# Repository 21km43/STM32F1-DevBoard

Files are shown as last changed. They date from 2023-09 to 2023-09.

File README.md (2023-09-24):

# STM32F1 Development Board

## Summary
Schematic and Board layout of STM32F1 Development Board. This project was created using [KiCAD](https://www.kicad.org/).

## MCU
STM32F103C8T6  
72Mhz, 20KB RAM, 64KB ROM  
[Datasheet](https://www.st.com/resource/en/datasheet/stm32f103cb.pdf)

## Board order at JLCPCB
I recommend ordering this board from JLCPCB. This board uses only Basic or Preferred Extended Parts excluding USB connector. Therefore, if you order this board, the price will be relatively low. 

When order this board, pay attention to the following.
1. If it is a small volume production (qty <= 30 or 50) and the parts on the bottom side are not assembled, order this board with Economic PCBA.
2. Order number is specified under the USB Connector. So you should select "Specify a location" for "Remove Order Number" option. 
3. Tooling holes (Radius 1.152mm hole) is already installed. So you should select "Added by Customer" for "Tooling holes" option.
4. For orders over 30 or 50 pieces, import tax should be imposed customs duties. (The tax border changes depending on the type of import and exchange rate.)

Order cost is depends on part cost and so on. For reference, the following is a rough estimate of the price when ordering the quantity (include shipping cost) (When using the $9 SMT coupon distributed by JLCPCB every month).
*  2 qty -> $12 ($6/brd)
*  5 qty -> $19 ($3.8/brd)
* 30 qty -> $82 ($2.8/brd) <- Customs duties may be imposed

## Features
* STM32F103C8T6 ARM Cortex M3
* `72 MHz` maximum frequency, `64 KB` of Flash memory, `20 KB` of SRAM
* `8 MHz` crystal (High-Speed Enternal Clock)
* `32.768 KHz` crystal (Low-Speed External Clock)
* Green LED `PB2` Active high
* Red power LED `PWR`
* 2x20 side pins
* Size: `50.80 mm x 20.32 mm`

* SPI Flash (Optional)
  * PA4 CS
  * PA6 MISO
  * PA7 MOSI
  * PA5 SCK

* USB Type-C
  * PA11 USB_DN
  * PA12 USB_DP

### Supported FLASH
* [W25QJVSSIQ](https://www.digikey.jp/ja/products/detail/winbond-electronics/W25Q32JVSSIQ/5803981)
* [IS25LP040E](https://akizukidenshi.com/catalog/g/gI-18046/)

Most SPI FLASH should be available. Check FLASH pinout before assemble.

## Parts List
You can see parts list from the BOM below.  
[Parts List](/production/bom.csv)

## Board Image
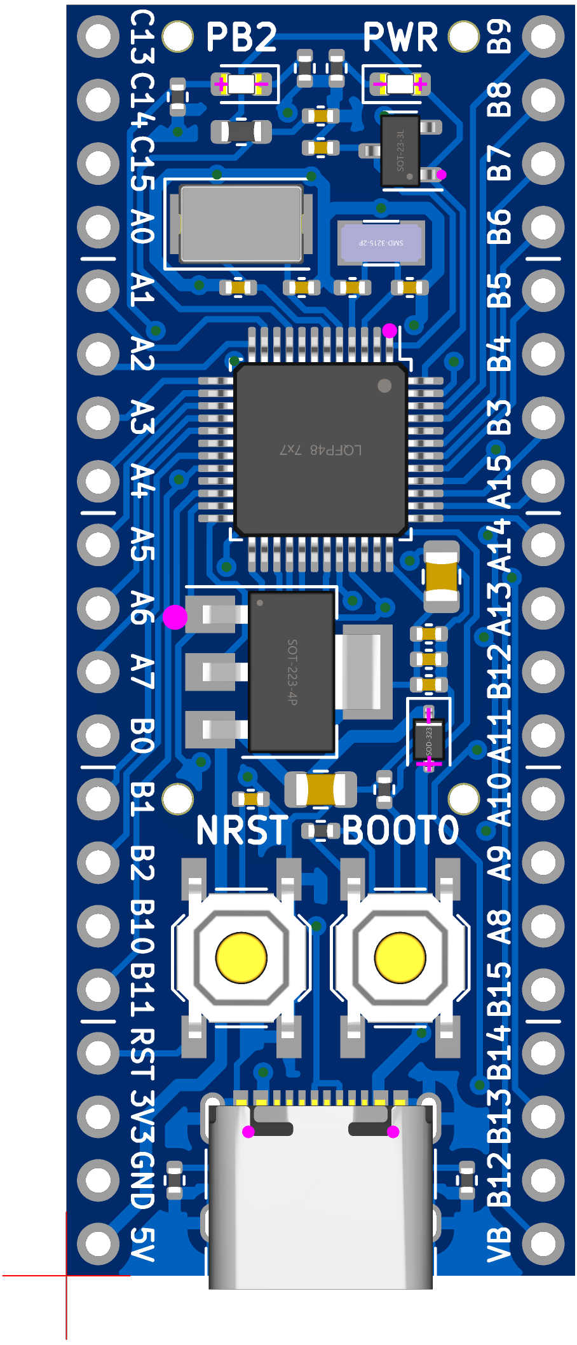
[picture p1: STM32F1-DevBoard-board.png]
Board Image


## LICENSE
[MIT LICENSE](/LICENSE)  
You may use it freely for personal use, but if you wish to use it for commercial purposes, I would appreciate it if you could contact us.

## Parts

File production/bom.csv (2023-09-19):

Designator | Footprint | Quantity | Value | LCSC Part #
C1, C2 | 0402 | 2 | 10pF | C32949
C10, C13, C5, C7, C8, C9 | 0402 | 6 | 100nF | C1525
C11, C12 | 0805 | 2 | 22uF | C45783
C3, C4 | 0402 | 2 | 20pF | C1554
C6 | 0603 | 1 | 100nF | C14663
D1 | D_SOD-323 | 1 | 1N5819WS | C191023
D3 | SOT-23 | 1 | BAT54C,215 | C37704
FB1 | 0603 | 1 | FerriteBead | C1002
J1 | USB_C_Receptacle_XKB_U262-16XN-4BVC11 | 1 | USB_C_Receptacle_USB2.0 | C2765186
LED1 | 0603 | 1 | 19-217/GHC-YR1S2/3T | C72043
LED2 | 0603 | 1 | KT-0603R | C2286
R1, R2, R4, R5 | 0402 | 4 | 10kΩ | C25744
R3, R6 | 0402 | 2 | 5.1kΩ | C25905
R7 | 0402 | 1 | 1.5kΩ | C25867
SW1, SW2 | SW_SPST_TL3342 | 2 | SW_Push | C318884
U1 | LQFP-48_7x7mm_P0.5mm | 1 | STM32F103C8T6 | C8734
U2 | SOT-223-3_TabPin2 | 1 | AMS1117-3.3 | C6186
U3 | SOIC-8_5.23x5.23mm_P1.27mm | 1 | W25Q32JVSS
XTAL1 | Crystal_SMD_3215-2Pin_3.2x1.5mm | 1 | 32.768KHz | C32346
XTAL2 | Crystal_SMD_5032-2Pin_5.0x3.2mm | 1 | 8MHz | C115962

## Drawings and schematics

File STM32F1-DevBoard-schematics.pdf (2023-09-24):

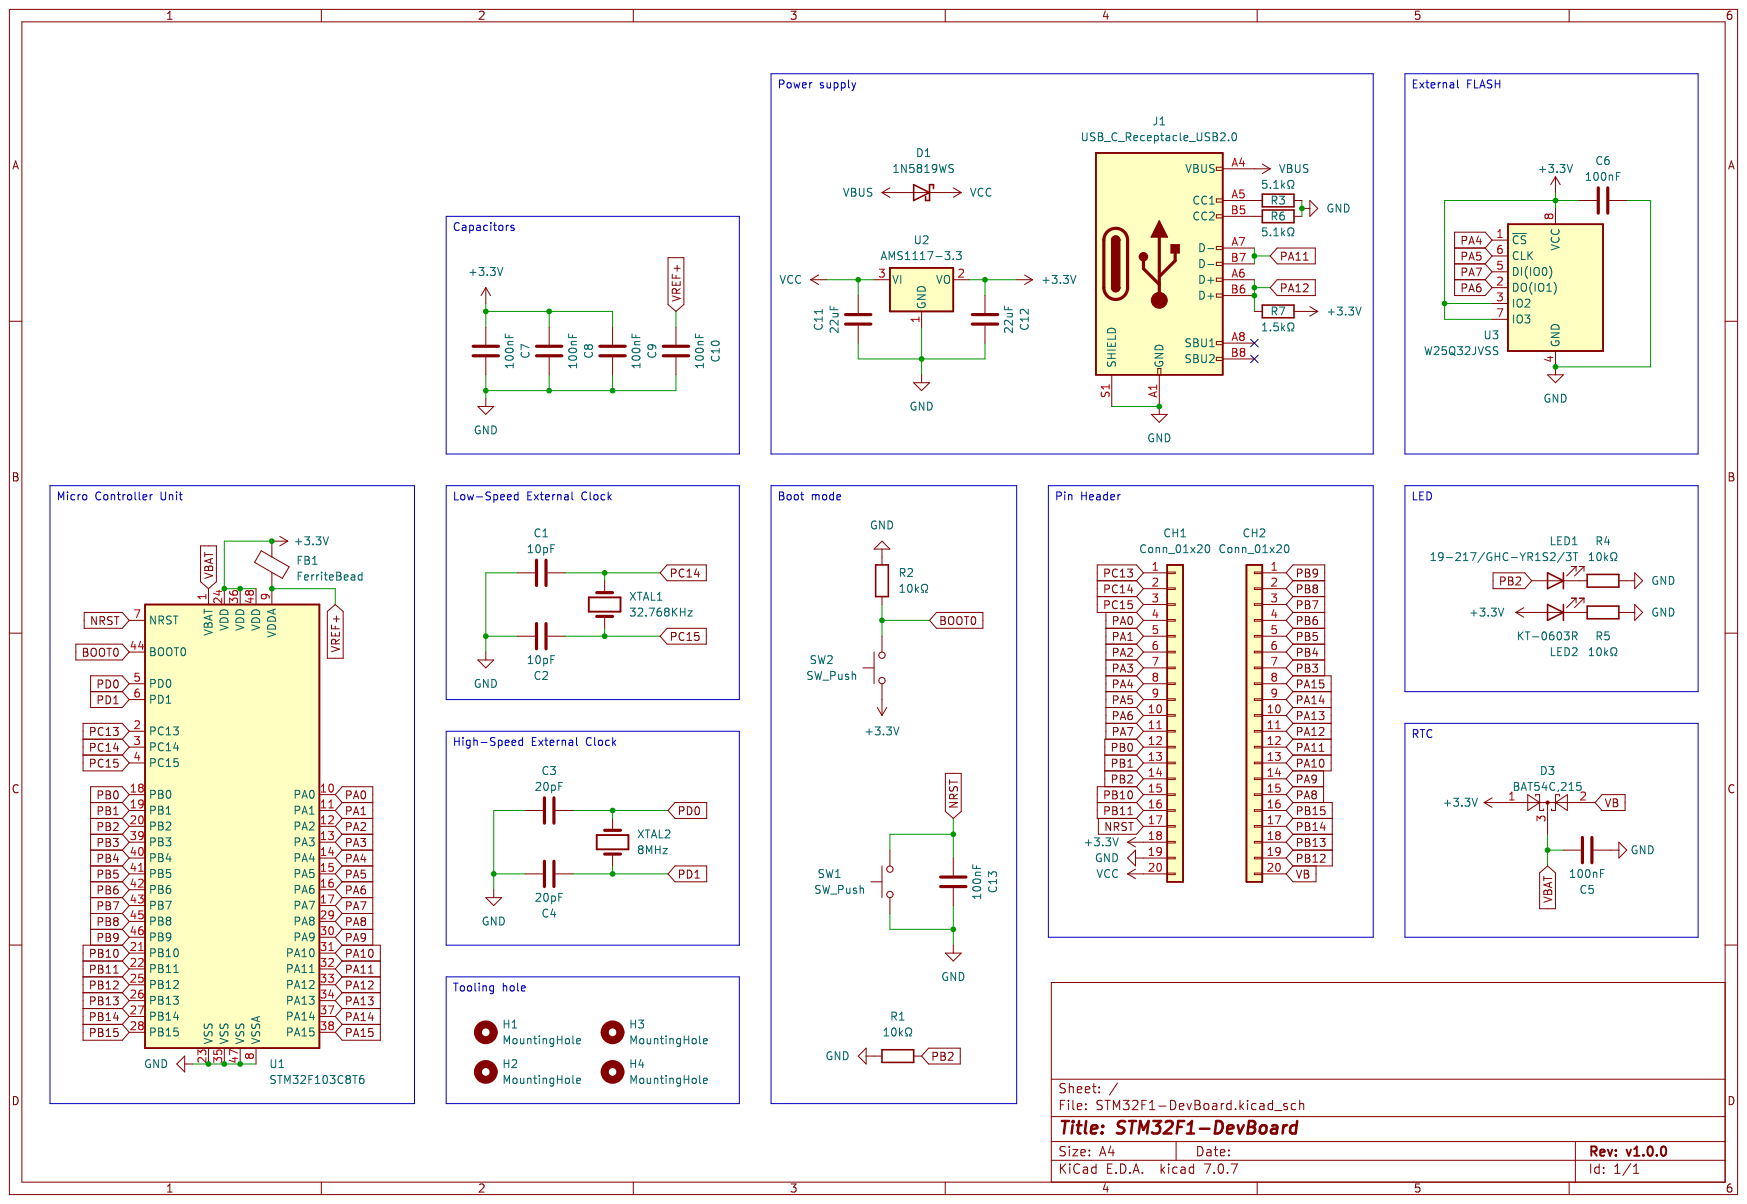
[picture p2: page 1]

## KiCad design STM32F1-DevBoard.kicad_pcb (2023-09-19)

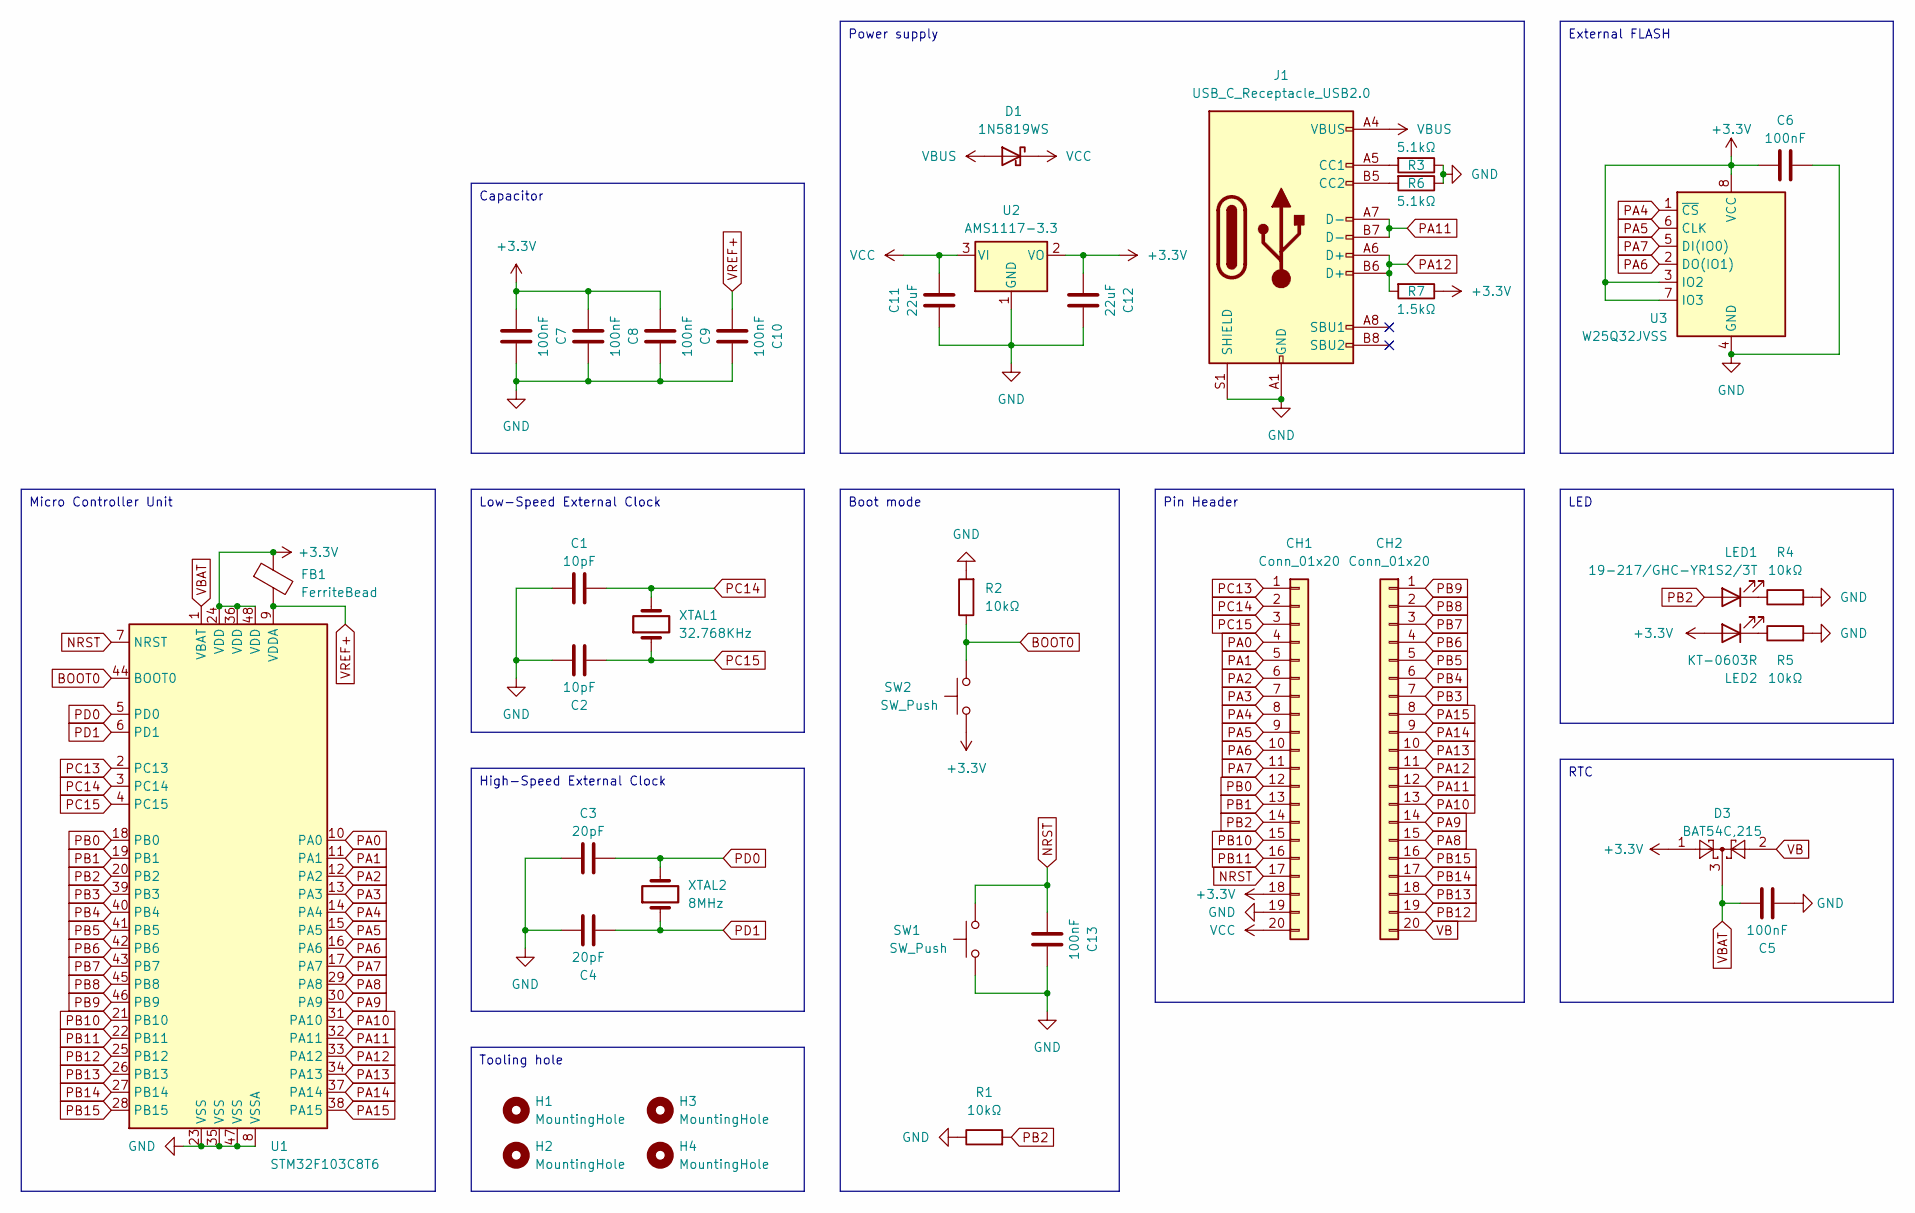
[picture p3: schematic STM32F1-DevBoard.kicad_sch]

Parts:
C1, C2: 10pF; C_0402_1005Metric; LCSC C32949
C3, C4: 20pF; C_0402_1005Metric; LCSC C1554
C5, C7, C8, C9, C10, C13: 100nF; C_0402_1005Metric; LCSC C1525
C6: 100nF; C_0603_1608Metric_Pad1.08x0.95mm_HandSolder; LCSC C14663
C11, C12: 22uF; C_0805_2012Metric; LCSC C45783
CH1, CH2: Conn_01x20; PinHeader_1x20_P2.54mm_Vertical
D1: 1N5819WS; D_SOD-323; LCSC C191023
D3: BAT54C,215; SOT-23; LCSC C37704
FB1: FerriteBead; L_0603_1608Metric; LCSC C1002
H1, H2, H3, H4: MountingHole; MountingHole_2.2mm_M2
J1: USB_C_Receptacle_USB2.0; USB_C_Receptacle_XKB_U262-16XN-4BVC11; LCSC C2765186
LED1: 19-217/GHC-YR1S2/3T; LED_0603_1608Metric; LCSC C72043
LED2: KT-0603R; LED_0603_1608Metric; LCSC C2286
R1, R2, R4, R5: 10kΩ; R_0402_1005Metric; LCSC C25744
R3, R6: 5.1kΩ; R_0402_1005Metric; LCSC C25905
R7: 1.5kΩ; R_0402_1005Metric; LCSC C25867
SW1, SW2: SW_Push; SW_SPST_TL3342; LCSC C318884
U1: STM32F103C8T6; LQFP-48_7x7mm_P0.5mm; LCSC C8734
U2: AMS1117-3.3; SOT-223-3_TabPin2; LCSC C6186
U3: W25Q32JVSS; SOIC-8_5.23x5.23mm_P1.27mm
XTAL1: 32.768KHz; Crystal_SMD_3215-2Pin_3.2x1.5mm; LCSC C32346
XTAL2: 8MHz; Crystal_SMD_5032-2Pin_5.0x3.2mm; LCSC C115962

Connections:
+3.3V: C6.1, C7.1, C8.1, C9.1, C12.1, CH1.18, D3.1, FB1.1, LED2.2 (A), R7.1, SW2.1, U1.24 (VDD), U1.36 (VDD), U1.48 (VDD), U2.2 (VO), U3.3 (IO2), U3.7 (IO3), U3.8 (VCC)
BOOT0: R2.1, SW2.2, U1.44 (BOOT0)
GND: C1.1, C2.2, C3.1, C4.2, C5.1, C6.2, C7.2, C8.2, C9.2, C10.2, C11.2, C12.2, C13.2, CH1.19, J1.A1 (GND), J1.A12 (GND), J1.B1 (GND), J1.B12 (GND), J1.S1 (SHIELD), R1.1, R2.2, R3.1, R4.2, R5.2, R6.1, SW1.1, U1.8 (VSSA), U1.23 (VSS), U1.35 (VSS), U1.47 (VSS), U2.1 (GND), U3.4 (GND)
NRST: C13.1, CH1.17, SW1.2, U1.7 (NRST)
unnamed: J1.A5 (CC1), R3.2
unnamed: J1.B5 (CC2), R6.2
unnamed: LED1.1 (K), R4.1
unnamed: LED2.1 (K), R5.1
PA0: CH1.4, U1.10 (PA0)
PA1: CH1.5, U1.11 (PA1)
PA2: CH1.6, U1.12 (PA2)
PA3: CH1.7, U1.13 (PA3)
PA4: CH1.8, U1.14 (PA4), U3.1 (~CS)
PA5: CH1.9, U1.15 (PA5), U3.6 (CLK)
PA6: CH1.10, U1.16 (PA6), U3.2 (DO(IO1))
PA7: CH1.11, U1.17 (PA7), U3.5 (DI(IO0))
PA8: CH2.15, U1.29 (PA8)
PA9: CH2.14, U1.30 (PA9)
PA10: CH2.13, U1.31 (PA10)
PA11: CH2.12, J1.A7 (D-), J1.B7 (D-), U1.32 (PA11)
PA12: CH2.11, J1.A6 (D+), J1.B6 (D+), R7.2, U1.33 (PA12)
PA13: CH2.10, U1.34 (PA13)
PA14: CH2.9, U1.37 (PA14)
PA15: CH2.8, U1.38 (PA15)
PB0: CH1.12, U1.18 (PB0)
PB1: CH1.13, U1.19 (PB1)
PB2: CH1.14, LED1.2 (A), R1.2, U1.20 (PB2)
PB3: CH2.7, U1.39 (PB3)
PB4: CH2.6, U1.40 (PB4)
PB5: CH2.5, U1.41 (PB5)
PB6: CH2.4, U1.42 (PB6)
PB7: CH2.3, U1.43 (PB7)
PB8: CH2.2, U1.45 (PB8)
PB9: CH2.1, U1.46 (PB9)
PB10: CH1.15, U1.21 (PB10)
PB11: CH1.16, U1.22 (PB11)
PB12: CH2.19, U1.25 (PB12)
PB13: CH2.18, U1.26 (PB13)
PB14: CH2.17, U1.27 (PB14)
PB15: CH2.16, U1.28 (PB15)
PC13: CH1.1, U1.2 (PC13)
PC14: C1.2, CH1.2, U1.3 (PC14), XTAL1.2
PC15: C2.1, CH1.3, U1.4 (PC15), XTAL1.1
PD0: C3.2, U1.5 (PD0), XTAL2.2
PD1: C4.1, U1.6 (PD1), XTAL2.1
VB: CH2.20, D3.2
VBAT: C5.2, D3.3, U1.1 (VBAT)
VBUS: D1.2 (A), J1.A4 (VBUS), J1.A9 (VBUS), J1.B4 (VBUS), J1.B9 (VBUS)
VCC: C11.1, CH1.20, D1.1 (K), U2.3 (VI)
VREF+: C10.1, FB1.2, U1.9 (VDDA)

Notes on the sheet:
External FLASH
Power supply
Pin Header
Tooling hole
RTC
High-Speed External Clock
Micro Controller Unit
Boot mode
LED
Capacitor
Low-Speed External Clock

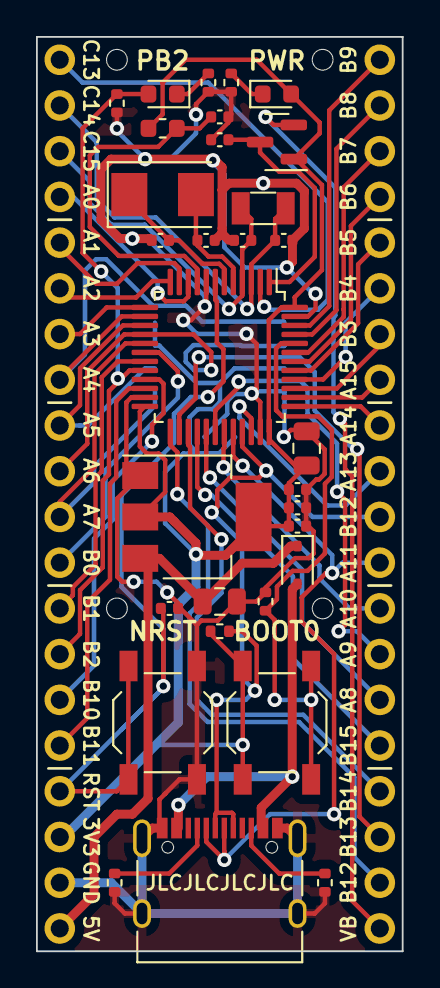
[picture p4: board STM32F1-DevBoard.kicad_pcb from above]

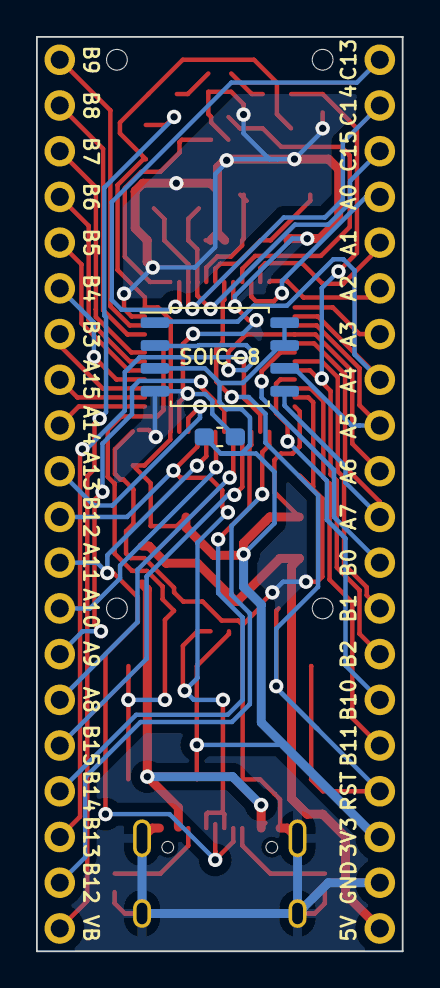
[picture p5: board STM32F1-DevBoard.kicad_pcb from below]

Board: 2 copper layers, 20.3 x 50.8 mm, 39 parts (4 on the bottom side), 50 nets.
